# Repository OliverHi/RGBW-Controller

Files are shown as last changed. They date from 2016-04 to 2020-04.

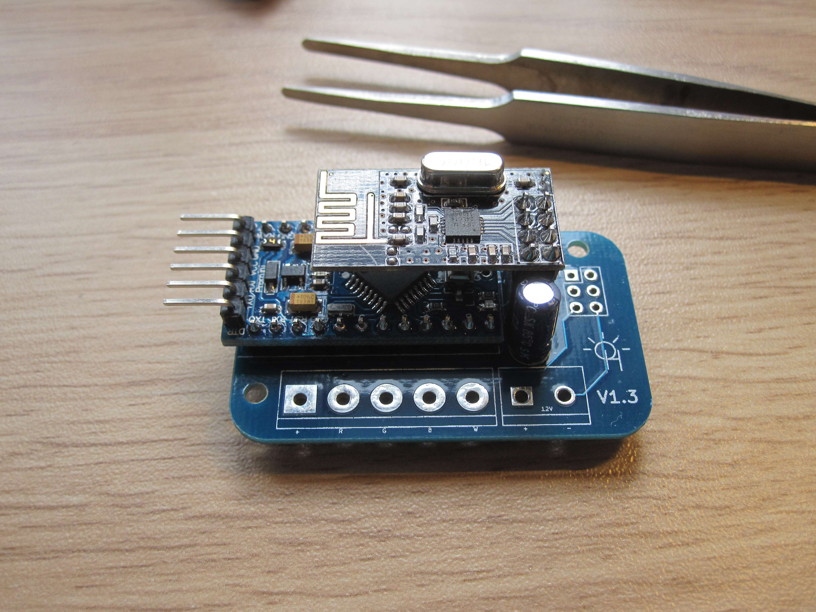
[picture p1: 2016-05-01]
Pictures/RGBWController004.jpg

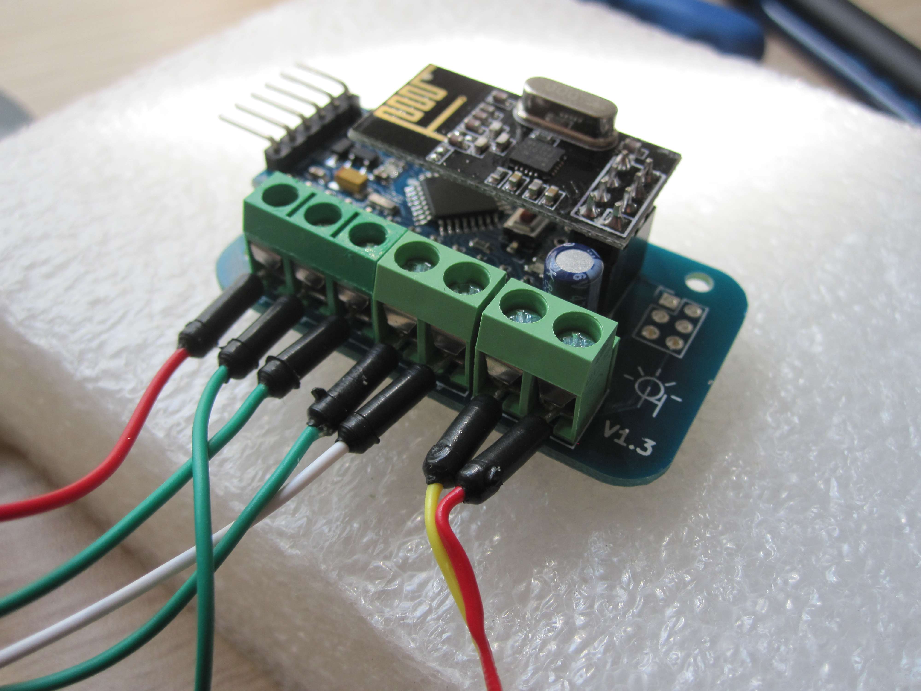
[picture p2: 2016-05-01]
Pictures/RGBWController012.jpg

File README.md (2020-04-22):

# Analog-RGBW-Controller
This is my rgbw controller project, where I am building a mysensors node to controll an analog RGBW led strip. 
The hardware is build around the arduino pro mini and NRF24L01+. 
The software is build on the MySensors project and is currently designed to work with Domoticz, Openhab 2 and homeAssistant (experimental) as a controller.

More infos can be found here: https://www.openhardware.io/view/74/MySensors-RGBW-Controller

## Project frozen/final
This project is done from my side. It has been working for years but I switched to another solution so I won't update this anymore. Feel free to send me Pull Requests though if you want anything updated or fork this repo.

If you are looking for a replacement follow me on [my blog](https://thesmarthomejourney.com/blog/) to see my current solution.

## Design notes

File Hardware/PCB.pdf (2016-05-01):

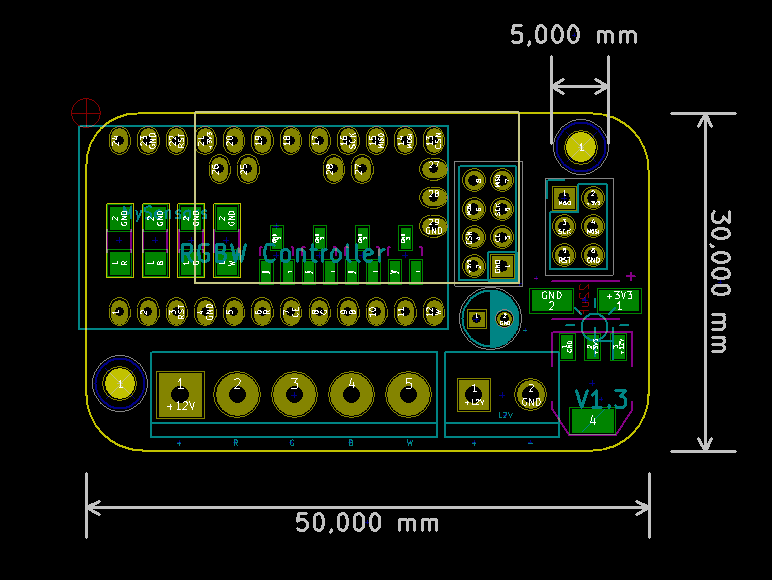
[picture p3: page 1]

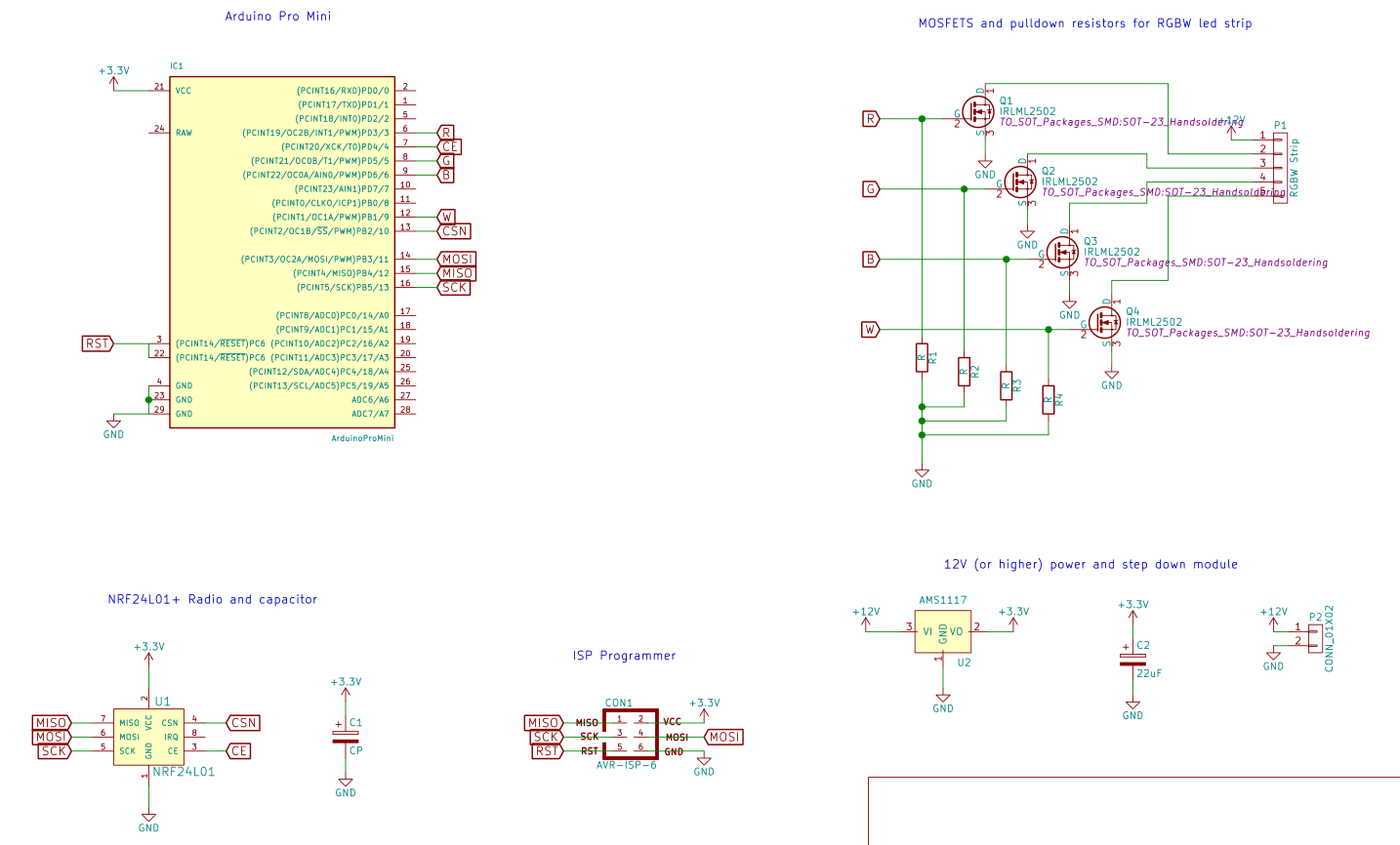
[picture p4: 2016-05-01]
Hardware/SchaltplanRGBW.PNG

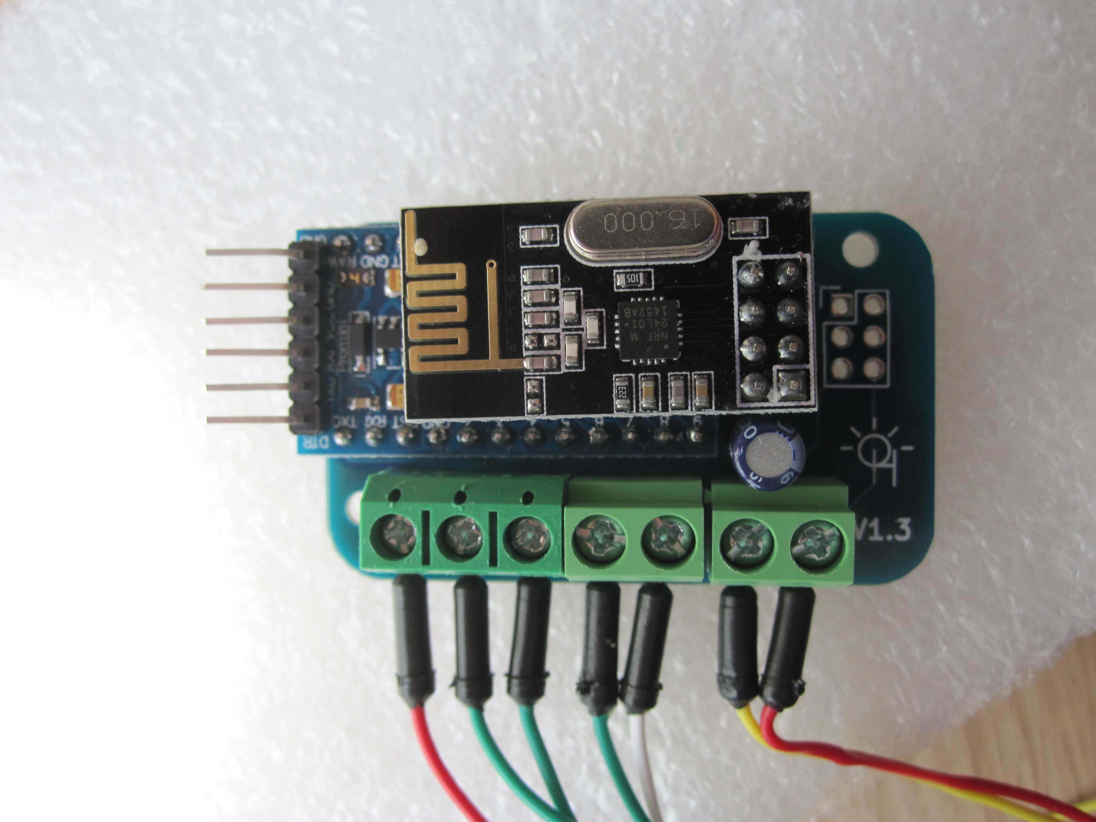
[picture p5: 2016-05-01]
Pictures/RGBWController013.jpg

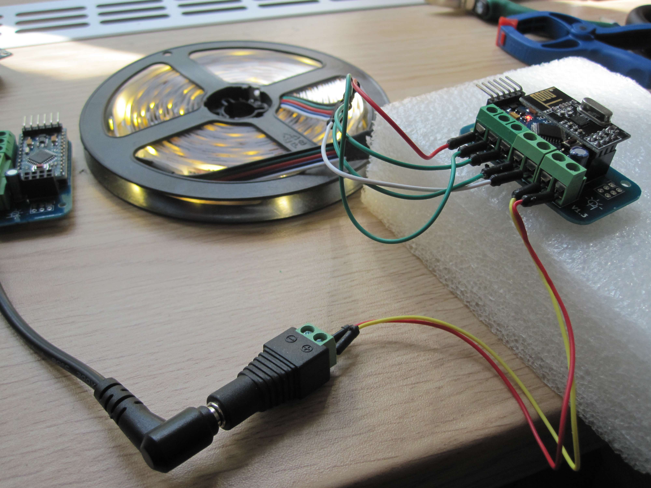
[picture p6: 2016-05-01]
Pictures/RGBWController011.jpg

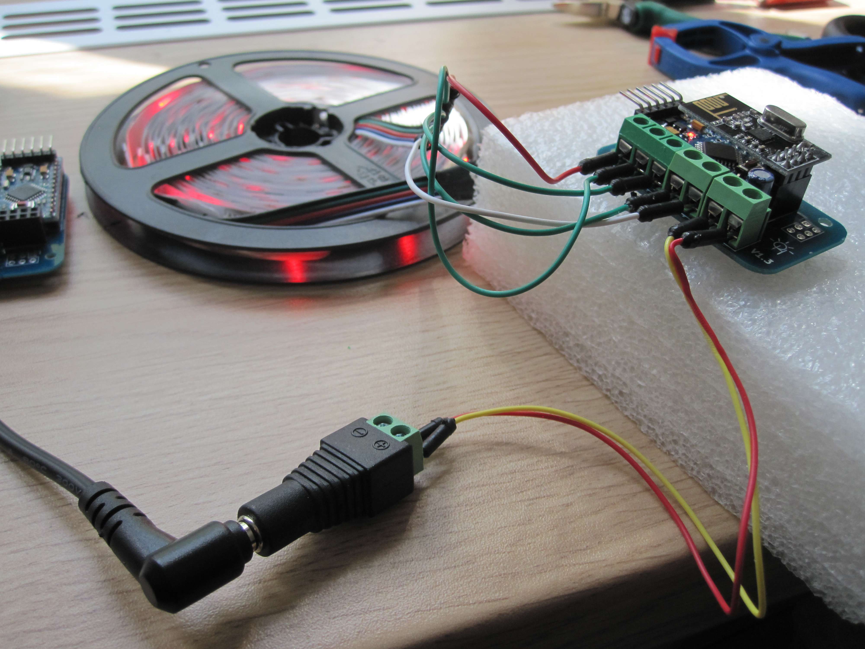
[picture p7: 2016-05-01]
Pictures/RGBWController010.jpg

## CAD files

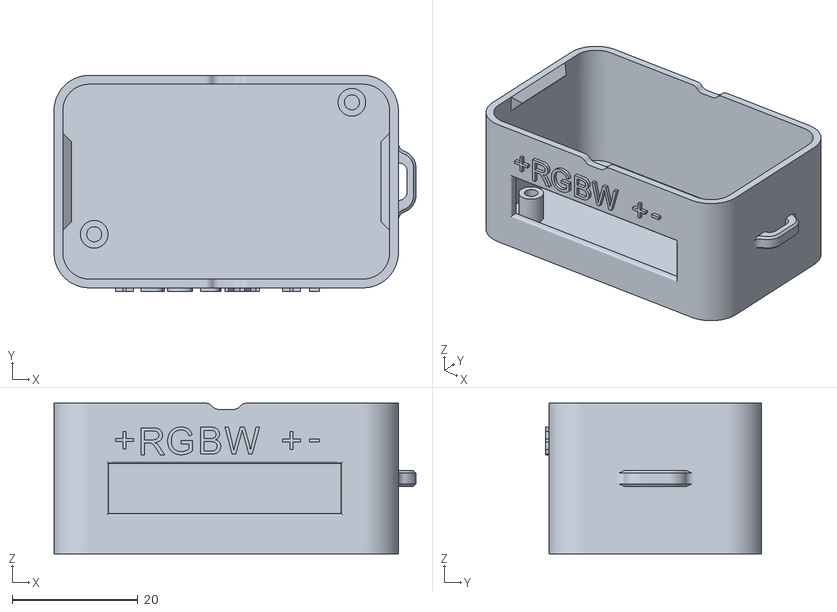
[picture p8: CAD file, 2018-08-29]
Hardware/Case/rgbwCaseBottomV2.stl
57.6 x 34.4 x 24.0

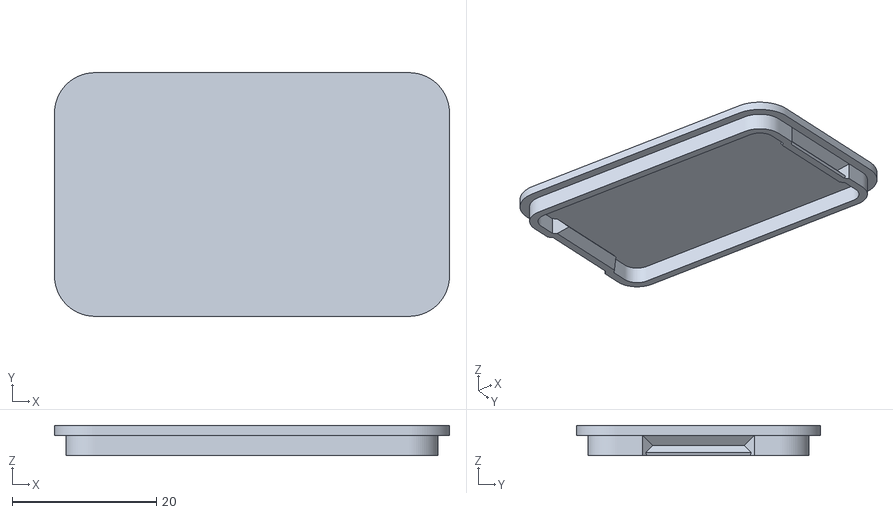
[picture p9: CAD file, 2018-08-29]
Hardware/Case/rgbwCaseTopV2.stl
54.8 x 33.8 x 4.20

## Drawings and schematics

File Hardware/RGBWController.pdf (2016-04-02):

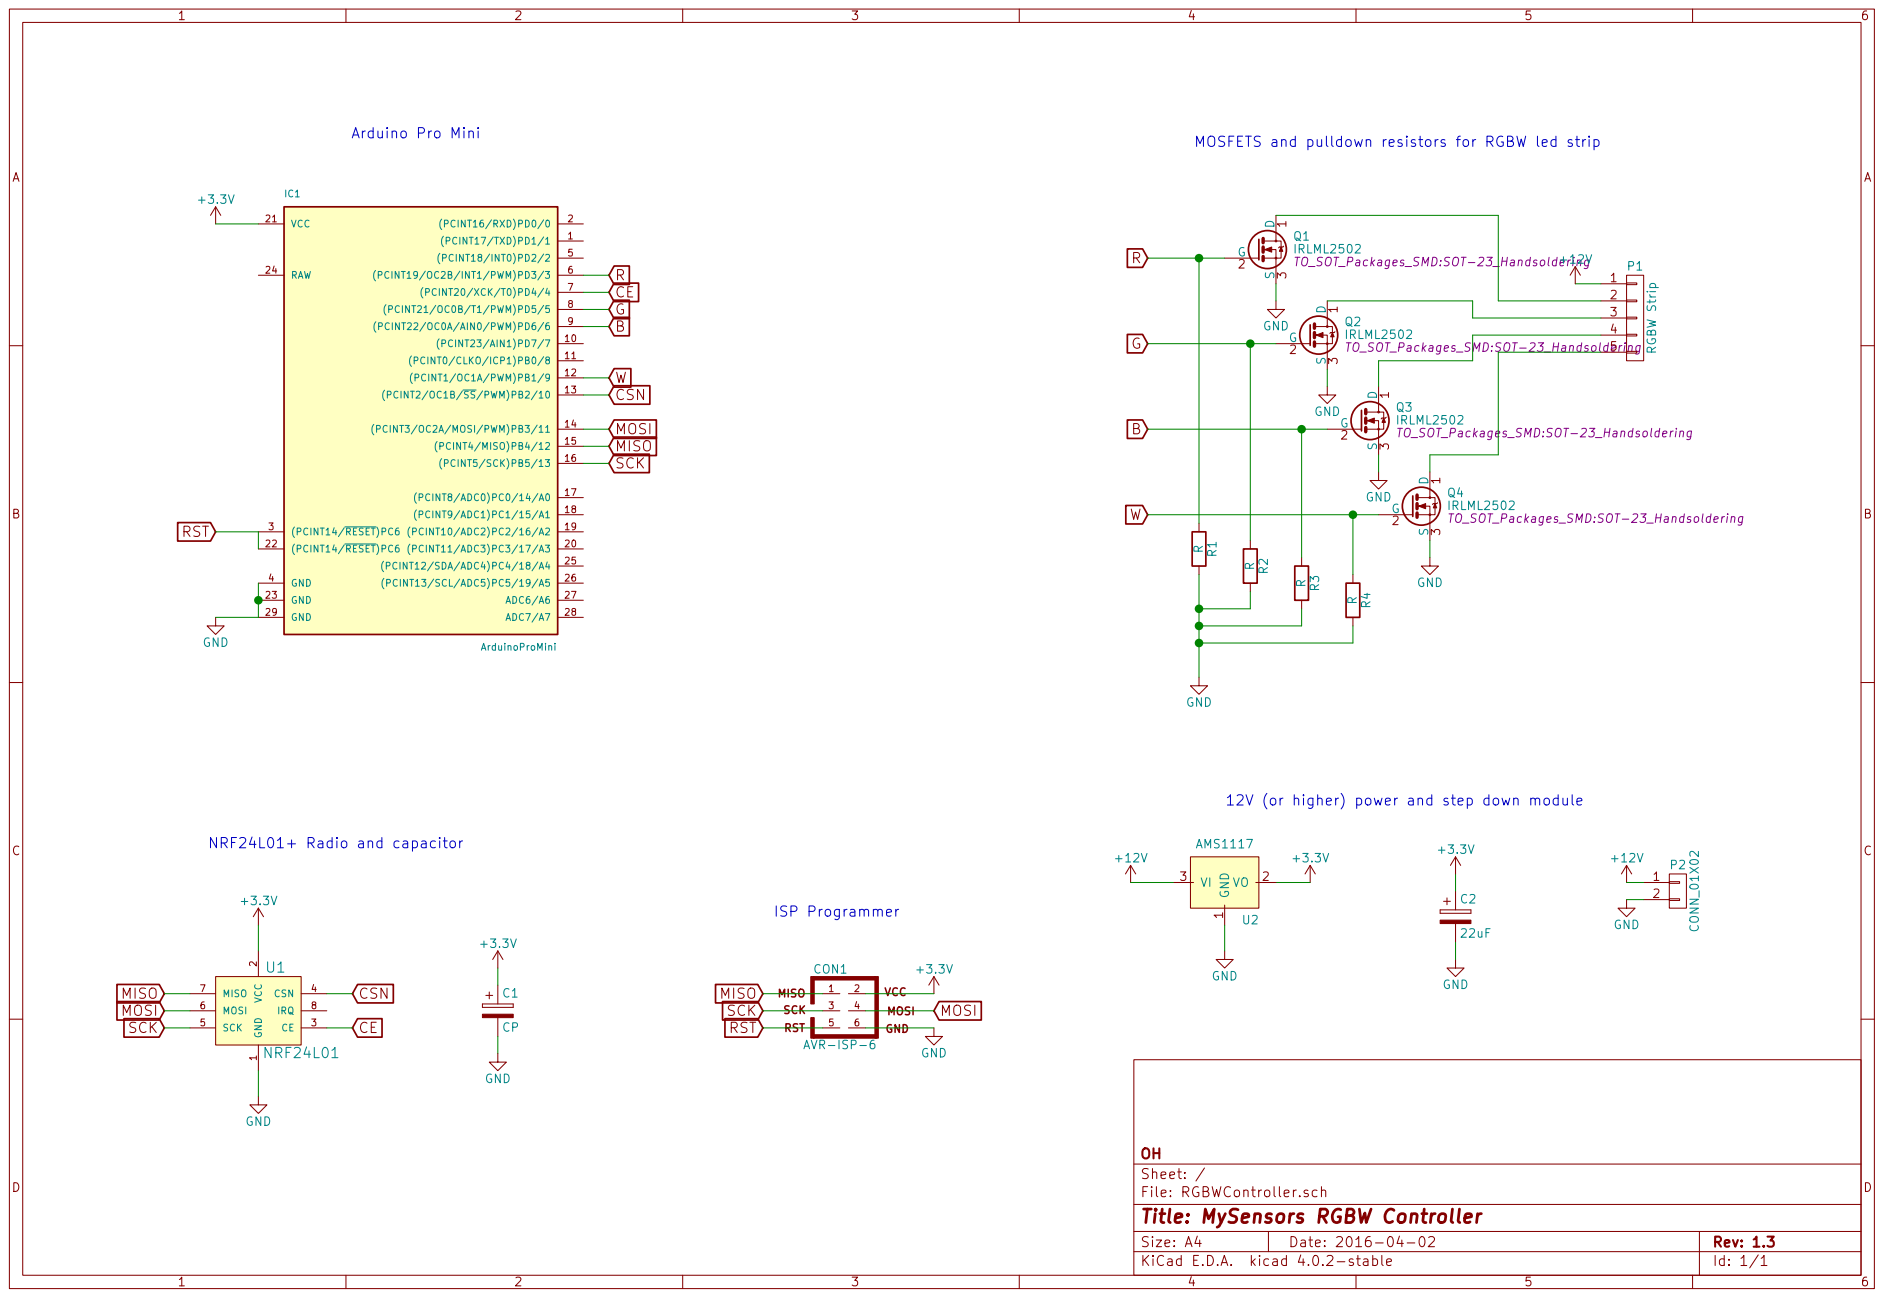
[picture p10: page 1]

Arduino Pro Mini NRF24L01+ Radio and capacitor

MOSFETS and pulldown resistors for RGBW led strip

RR4 RR3 RR2 RR1 GND GND GND GND GND

12V (or higher) power and step down module

2 CE 3 CSN 4 SCK 5 MOSI 6 MISO 7

Id: 1/1 Title: MySensors RGBW Controller File: RGBWController.sch Sheet: / OH

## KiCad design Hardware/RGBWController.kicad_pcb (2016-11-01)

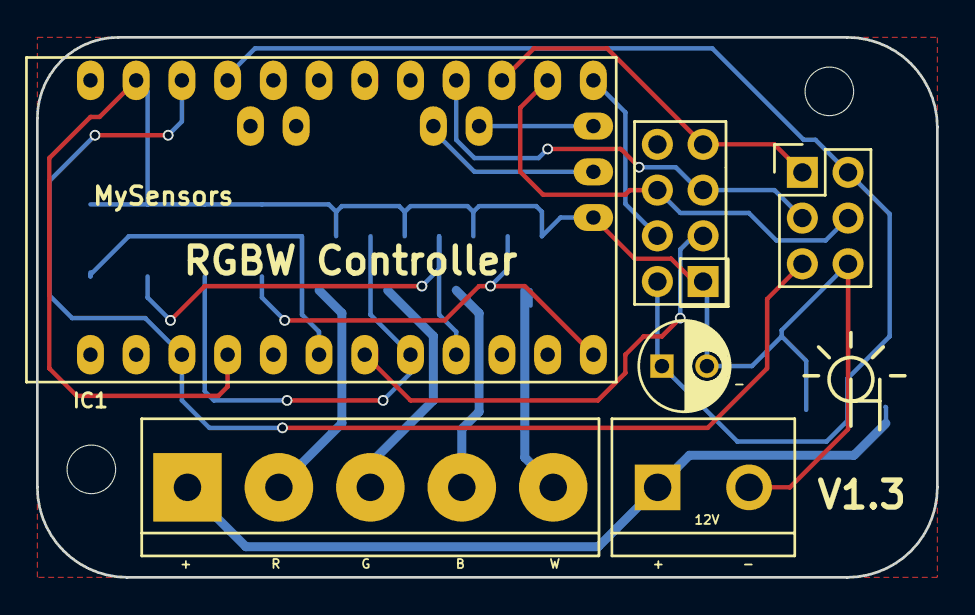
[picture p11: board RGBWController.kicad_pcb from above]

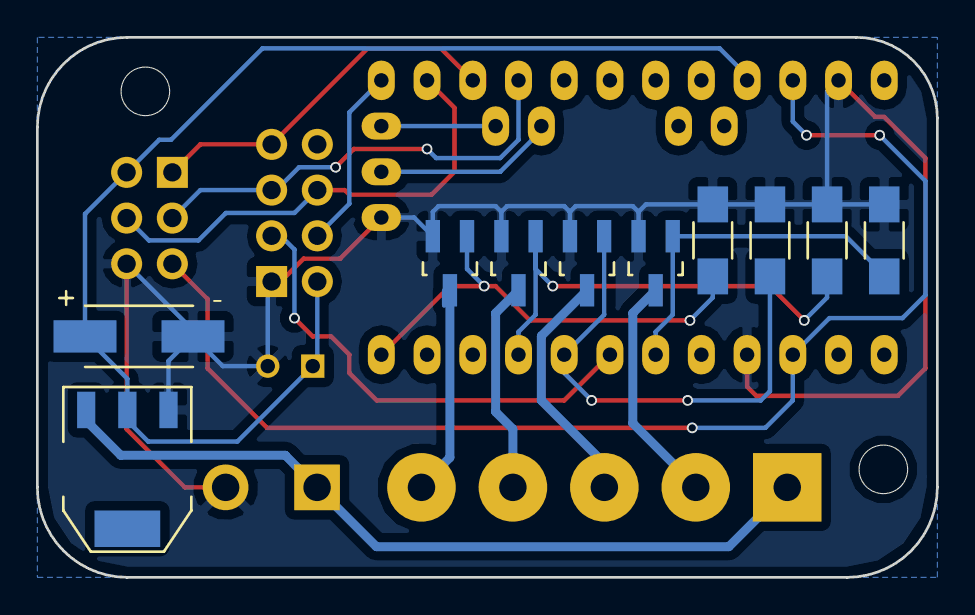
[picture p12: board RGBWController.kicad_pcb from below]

Board: 2 copper layers, 50.0 x 30.0 mm, 16 parts (10 on the bottom side), 17 nets.

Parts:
C1: CP; C_Radial_D5_L11_P2.5
C2: 22uF; TantalC_SizeC_EIA-6032_HandSoldering
CON1: AVR-ISP-6; Pin_Header_Straight_2x03
IC1: ArduinoProMini; pro_mini
P1: RGBW Strip; bornier5
P2: CONN_01X02; bornier2
Q1, Q2, Q3, Q4: IRLML2502; SOT-23_Handsoldering
R1, R2, R3, R4: R; R_1206_HandSoldering
U1: NRF24L01
U2: AMS1117; SOT-223

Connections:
+3V3: C1.1, C2.1, CON1.2, IC1.21, U1.2, U2.2
+12V: P1.1, P2.1, U2.3
B: IC1.9, Q3.1, R3.1
CE: IC1.7, U1.3
CSN: IC1.13, U1.4
G: IC1.8, Q2.1, R2.1
GND: C1.2, C2.2, CON1.6, IC1.4, IC1.23, IC1.29, P2.2, Q1.2, Q2.2, Q3.2, Q4.2, R1.2, R2.2, R3.2, R4.2, U1.1, U2.1
MISO: CON1.1, IC1.15, U1.7
MOSI: CON1.4, IC1.14, U1.6
unnamed: P1.2, Q1.3
unnamed: P1.3, Q2.3
unnamed: P1.4, Q3.3
unnamed: P1.5, Q4.3
R: IC1.6, Q1.1, R1.1
RST: CON1.5, IC1.3, IC1.22
SCK: CON1.3, IC1.16, U1.5
W: IC1.12, Q4.1, R4.1

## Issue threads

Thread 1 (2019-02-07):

Ask about hardwear

pepeEL, 2019-02-07:
Hi
I ask for you. In your project use arduino pro mini 5V or 3,3V ? I want use it with radio  RFM69HW on adapter from NRF24 to RFM69.

OliverHi, 2019-02-08:
> Hi
> I ask for you. In your project use arduino pro mini 5V or 3,3V ? I want use it with radio RFM69HW on adapter from NRF24 to RFM69.

In this case I used the 3.3V version. Take a look at the [schematics](https://github.com/OliverHi/RGBW-Controller/blob/master/Hardware/SchaltplanRGBW.PNG). I decided to do that because the NRF24 needs 3.3V and this way I can use the same power source (a AMS1117 3.3V converter). You could go with 5V though if the RFM69 can handle that and use the 5V pro mini or the onboard converter.

I can't help you with the RFM69HW modules though as I have been using NRF24's only.

pepeEL, 2019-02-08:
Thanks for reply. Rfm69 also use3. 3v
Thanks

pepeEL, 2019-02-08:
I build your project and use radio RFM69HW with this adapter:
https://www.openhardware.io/view/601/NRF24-to-RFM69-adapter
and Arduino Mini Pro 3,3V and not working. This device not communicate with my Gateway on my RPI3b+.

Ofcourse in RGBWDimmerV2.ino i change communicate type radio and add for my and also change to number 1 "#define ACK_COMMANDS 0 // set to 1/true " becuase i want use it with Home Assistant.

Tell me is any chance to you convert project also to use radio RFM69HW without adapter ?

Or can you share me project file to i can try rebuild it to use radio RFM69HW without adapter ?

pepeEL, 2019-02-09:
in serial monitor i have this after start....
 __  __       ____
|  \/  |_   _/ ___|  ___ _ __  ___  ___  _ __ ___
| |\/| | | | \___ \ / _ \ `_ \/ __|/ _ \| `__/ __|
| |  | | |_| |___| |  __/ | | \__ \  _  | |  \__ \
|_|  |_|\__, |____/ \___|_| |_|___/\___/|_|  |___/
        |___/                      2.2.0

16 MCO:BGN:INIT NODE,CP=RPNNA---,VER=2.2.0
26 TSM:INIT
28 TSF:WUR:MS=0
131 !TSM:INIT:TSP FAIL
133 TSM:FAIL:CNT=1
135 TSM:FAIL:DIS
137 TSF:TDI:TSL
10139 TSM:FAIL:RE-INIT
10141 TSM:INIT
10244 !TSM:INIT:TSP FAIL
10246 TSM:FAIL:CNT=2
10248 TSM:FAIL:DIS
10250 TSF:TDI:TSL
20254 TSM:FAIL:RE-INIT
20256 TSM:INIT
20361 !TSM:INIT:TSP FAIL
20363 TSM:FAIL:CNT=3
20365 TSM:FAIL:DIS
20367 TSF:TDI:TSL

pepeEL, 2019-02-09:
replace radio and now show
 __  __       ____
|  \/  |_   _/ ___|  ___ _ __  ___  ___  _ __ ___
| |\/| | | | \___ \ / _ \ `_ \/ __|/ _ \| `__/ __|
| |  | | |_| |___| |  __/ | | \__ \  _  | |  \__ \
|_|  |_|\__, |____/ \___|_| |_|___/\___/|_|  |___/
        |___/                      2.2.0

16 MCO:BGN:INIT NODE,CP=RPNNA---,VER=2.2.0
26 TSM:INIT
28 TSF:WUR:MS=0
30 TSM:INIT:TSP OK
32 TSM:FPAR
1034 TSF:MSG:SEND,255-255-255-255,s=255,c=3,t=7,pt=0,l=0,sg=0,ft=0,st=OK:
3043 !TSM:FPAR:NO REPLY
3045 TSM:FPAR
4048 TSF:MSG:SEND,255-255-255-255,s=255,c=3,t=7,pt=0,l=0,sg=0,ft=0,st=OK:
6060 !TSM:FPAR:NO REPLY
6062 TSM:FPAR
7065 TSF:MSG:SEND,255-255-255-255,s=255,c=3,t=7,pt=0,l=0,sg=0,ft=0,st=OK:
9074 !TSM:FPAR:NO REPLY
9076 TSM:FPAR
10078 TSF:MSG:SEND,255-255-255-255,s=255,c=3,t=7,pt=0,l=0,sg=0,ft=0,st=OK:
12087 !TSM:FPAR:FAIL
12089 TSM:FAIL:CNT=1
12091 TSM:FAIL:DIS
12093 TSF:TDI:TSL
22097 TSM:FAIL:RE-INIT
22099 TSM:INIT
22102 TSM:INIT:TSP OK
22104 TSM:FPAR
23107 TSF:MSG:SEND,255-255-255-255,s=255,c=3,t=7,pt=0,l=0,sg=0,ft=0,st=OK:
25116 !TSM:FPAR:NO REPLY
25118 TSM:FPAR
26120 TSF:MSG:SEND,255-255-255-255,s=255,c=3,t=7,pt=0,l=0,sg=0,ft=0,st=OK:
28129 !TSM:FPAR:NO REPLY
28131 TSM:FPAR
29134 TSF:MSG:SEND,255-255-255-255,s=255,c=3,t=7,pt=0,l=0,sg=0,ft=0,st=OK:
31145 !TSM:FPAR:NO REPLY
31148 TSM:FPAR
32151 TSF:MSG:SEND,255-255-255-255,s=255,c=3,t=7,pt=0,l=0,sg=0,ft=0,st=OK:
34160 !TSM:FPAR:FAIL
34162 TSM:FAIL:CNT=2
34164 TSM:FAIL:DIS
34166 TSF:TDI:TSL
44169 TSM:FAIL:RE-INIT
44171 TSM:INIT
44173 TSM:INIT:TSP OK
44175 TSM:FPAR
45178 TSF:MSG:SEND,255-255-255-255,s=255,c=3,t=7,pt=0,l=0,sg=0,ft=0,st=OK:
47190 !TSM:FPAR:NO REPLY
47192 TSM:FPAR
48195 TSF:MSG:SEND,255-255-255-255,s=255,c=3,t=7,pt=0,l=0,sg=0,ft=0,st=OK:
50204 !TSM:FPAR:NO REPLY
50206 TSM:FPAR
51208 TSF:MSG:SEND,255-255-255-255,s=255,c=3,t=7,pt=0,l=0,sg=0,ft=0,st=OK:
53217 !TSM:FPAR:NO REPLY
53219 TSM:FPAR
54222 TSF:MSG:SEND,255-255-255-255,s=255,c=3,t=7,pt=0,l=0,sg=0,ft=0,st=OK:
56233 !TSM:FPAR:FAIL
56236 TSM:FAIL:CNT=3
56238 TSM:FAIL:DIS
56240 TSF:TDI:TSL
66244 TSM:FAIL:RE-INIT
66246 TSM:INIT
66248 TSM:INIT:TSP OK
66250 TSM:FPAR
67252 TSF:MSG:SEND,255-255-255-255,s=255,c=3,t=7,pt=0,l=0,sg=0,ft=0,st=OK:
69261 !TSM:FPAR:NO REPLY
69263 TSM:FPAR
70266 TSF:MSG:SEND,255-255-255-255,s=255,c=3,t=7,pt=0,l=0,sg=0,ft=0,st=OK:
72278 !TSM:FPAR:NO REPLY
72280 TSM:FPAR
73283 TSF:MSG:SEND,255-255-255-255,s=255,c=3,t=7,pt=0,l=0,sg=0,ft=0,st=OK:
75292 !TSM:FPAR:NO REPLY
75294 TSM:FPAR
76296 TSF:MSG:SEND,255-255-255-255,s=255,c=3,t=7,pt=0,l=0,sg=0,ft=0,st=OK:

OliverHi, 2019-04-20:
All files of the project are in this repo. Feel free to change and update stuff (as long as you link my repo if you upload your code). I wont create an extra version for the RFM69 (no time). It should just work though with what you posted though I think. But for more help please head over to the mysensors forum

Closed 2019-04-20.

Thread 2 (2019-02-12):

Implement button to turn leds color WHITE

pepeEL, 2019-02-12:
Hi
Is any chance to implement in your sketch option to add manual button to enable LEDS color WHITE ?
Any color i want to setup by gateway but on the wall i want mount switch to enable color white and also to disable.
Please add this if you can... In sketch setup pin on which button works and also color which should be turn on....

OliverHi, 2019-04-20:
What do you mean by Leds color white? If you want to add a button to your board that switches on the white lights just add standard (non blocking) button code (a quick search for arduino button should get you there) and call the void `updateColor(const char* newColor)` with your color of choice. Or send a message to your gateway and handle the logic in your controller (better solution imho)

pepeEL, 2019-04-21:
Yes I want add button to RGBW which turn on led with color white.
But how add it and how configure it in sketch and also how phisical add to this arduino?

OliverHi, 2019-04-21:
This is really outside of the scope of this repo. I told you how to do it, I wont code this for you. Once you have tried and it still does not work there are enough forums out there for arduino questions.

Closed 2019-04-20.

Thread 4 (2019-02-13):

Bug in project PCB

pepeEL, 2019-02-13:
I found one bug in your project PCB. Pin from radio nae IRQ should be connect on PCB to pin 2 ARDUINO. But it is not connect. Also when i use radio RFM69HW i also need connect PIN 2 Arduino to pin DI00 on radio RFM69HW. This should be correct... Now pin 9 from radio is not connect to any pin Arduino.

OliverHi, 2019-04-20:
You are right I think. The IRQ pin is not connected because it is not required when using the NRF24L01 which this board is based around. Maybe there are also other pins needed for the RFM69HW but I am not really supporting that.
This project is frozen from my side (as I am using other solutions now). But feel free to update everything you want (all code is in this repo) and create a pull request. I will review and merge it as soon as possible

Closed 2020-04-22.

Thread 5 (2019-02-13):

Initial state-OFF

pepeEL, 2019-02-13:
Hi
Is any chance to implement in sketch option to Node after connect power go to state OFF. Now it go to ON. In situation when power lost and come back all leds will be ON.

OliverHi, 2019-04-20:
Yes you can change the initial state of the node in my code. Have a look [at these lines.](https://github.com/OliverHi/RGBW-Controller/blob/3e6f01034f0cd9d36f983cb69602abfd6884ea8d/Software/RGBWDimmerV2/RGBWDimmerV2.ino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) Changing `target_values` and `values` according to your needs will get you there

pepeEL, 2019-04-21:
But if I want to have OFF when power is on how I must change this code initial and target?

OliverHi, 2019-04-21:
Those are RGBW values so of is 0 0 0 0. The rest you have to figure out on your own.

Closed 2019-04-20.

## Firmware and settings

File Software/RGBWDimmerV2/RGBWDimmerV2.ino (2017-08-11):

/**
Based on the MySensors Project: http://www.mysensors.org

This sketch controls a (analog)RGBW strip by listening to new color/dimmer/status values from a (domoticz/openhab/Homeassistant) controller and then fading to the new color.

Version 2.2 - Added initial state messages to the controller and ack messages to support home-assistant, also added better nonlinear fading (thanks to Jan Gatzke from the forum)
Version 2.1 - Changed conversion to also work with openhab(2)
Version 2.0 - Updated to MySensors 2 and changed fading
Version 1.0 - Changed pins and gw definition
Version 0.9 - Oliver Hilsky
*/


#define SN   "Name"
#define SV   "v2.2 0108017"

// library settings
#define MY_RF24_CE_PIN 4                  // Radio specific settings for RF24 - changed this!
#define MY_RF24_CS_PIN 10                 // Radio specific settings for RF24 (you'll find similar config for RFM69)
#define MY_RADIO_NRF24                    // Use the nrf24 to send messages
#define MY_DEBUG                          // Enables debug messages in the serial log
#define MY_BAUD_RATE  115200              // Sets the serial baud rate for console
#define MY_SIGNING_SOFT                   // Enables software signing
#define MY_SIGNING_REQUEST_SIGNATURES     // Always request signing from gateway
#define MY_SIGNING_SOFT_RANDOMSEED_PIN 7  // floating pin for randomness
#define MY_SIGNING_NODE_WHITELISTING {{.nodeId = GATEWAY_ADDRESS,.serial = {0x01,0x01,0x01,0x01,0x01,0x01,0x01,0x01,0x01}}} // add your gateway address here!


#include <SPI.h>
#include <MyConfig.h>
#include <MySensors.h>
#include <Vcc.h>

// ID for the presentation at the gateway
#define RGBW_ID 1

// Arduino pin attached to driver pins
#define RED_PIN 3 
#define WHITE_PIN 9
#define GREEN_PIN 5
#define BLUE_PIN 6
#define NUM_CHANNELS 4 // how many channels, RGBW=4 RGB=3...

// Smooth stepping between the values
#define STEP 1
#define INTERVAL 10

#define ACK_COMMANDS 0 // set to 1/true if you use home assistant. This will answer every message with the same, disable otherwise
   
// Stores the current color settings
byte channels[4] = {RED_PIN, GREEN_PIN, BLUE_PIN, WHITE_PIN};
byte values[4] = {0, 0, 0, 0}; // initial values -> makes white fade up to 100%
byte target_values[4] = {0, 0, 0, 255};
//Stores corrected values for each step from 0 to 255. See https://diarmuid.ie/blog/pwm-exponential-led-fading-on-arduino-or-other-platforms/
byte converted_values[256] = {0,0,0,0,0,0,0,0,0,0,0,0,0,0,0,0,0,0,0,1,1,1,1,1,1,1,1,1,1,1,1,1,1,1,1,1,1,1,1,1,1,1,1,2,2,2,2,2,2,2,2,2,2,2,2,2,2,2,3,3,3,3,3,3,3,3,3,3,3,3,4,4,4,4,4,4,4,4,4,5,5,5,5,5,5,5,5,6,6,6,6,6,6,7,7,7,7,7,7,8,8,8,8,8,9,9,9,9,9,10,10,10,10,11,11,11,11,12,12,12,13,13,13,13,14,14,14,15,15,15,16,16,17,17,17,18,18,19,19,20,20,20,21,21,22,22,23,23,24,24,25,26,26,27,27,28,29,29,30,31,31,32,33,34,34,35,36,37,38,38,39,40,41,42,43,44,45,46,47,48,49,50,51,52,54,55,56,57,58,60,61,62,64,65,67,68,70,71,73,75,76,78,80,81,83,85,87,89,91,93,95,97,99,101,104,106,108,111,113,116,118,121,123,126,129,132,135,138,141,144,147,150,154,157,161,164,168,171,175,179,183,187,191,195,200,204,209,213,218,223,228,233,238,243,249,255};

// Messages
MyMessage statusMessage(RGBW_ID, V_STATUS);
MyMessage dimmerMessage(RGBW_ID, V_DIMMER);
MyMessage colorMessage (RGBW_ID, V_RGBW);

// stores dimming level
byte dimming = 100;
byte target_dimming = 100;

// tracks if the strip should be on of off
boolean isOn = true;

// time tracking for updates
unsigned long lastupdate = millis();
     
void presentation() 
{
  // Present sketch (name, version)
  sendSketchInfo(SN, SV);				
       
  // Register sensors (id, type, description, ack back)
  present(RGBW_ID, S_RGBW_LIGHT);

  // get old values if this is just a restart
  request(RGBW_ID, V_RGBW);
}

void setup() {

  // Set all channels to output (pin number, type)
  for (int i = 0; i < NUM_CHANNELS; i++) {
    pinMode(channels[i], OUTPUT);
  }

  // init lights
  updateLights();
 
  Serial.println("Waiting for messages...");  
}

void loop()
{
  // and set the new light colors
  if (millis() > lastupdate + INTERVAL) {
    updateLights();
    lastupdate = millis();
  }

  // send initial state (needed to be detected by home assistant)
  static bool first_message_sent = false;

  if ( first_message_sent == false ) {
    Serial.println( "Sending initial state..." );
    sendinitialValuesToGateway();
    first_message_sent = true;
  }
}

void sendinitialValuesToGateway() {
  send(colorMessage.set("000000ff")); // full white
  send(statusMessage.set(isOn)); // on
  send(dimmerMessage.set(target_dimming)); // dimmed to start level
}

// callback function for incoming messages
void receive(const MyMessage &message) {

  Serial.print("Got a message - ");
  Serial.print("Messagetype is: ");
  Serial.println(message.type);

  // acknowledgement
  if (message.isAck())
  {
   	Serial.println("Got ack from gateway");
  }
  
  // new dim level
  else if (message.type == V_DIMMER) {
    Serial.println("Dimming to ");
    Serial.println(message.getString());
    updateDimmer(message.getByte());
  }

  // on / off message
  else if (message.type == V_STATUS) {
    updateStatus(message.getInt());
    
    String statusMsg = "Turning light ";
    statusMsg += (message.getInt() == 0 ? ("off") : ("on"));
    Serial.println(statusMsg);
  }

  // new color value
  else if (message.type == V_RGBW) {    
    Serial.println("Got new color");

    updateColor(message.getString());
  }  
}

void updateDimmer(byte newDimValue) {
  target_dimming = newDimValue;

  if (ACK_COMMANDS) {
    send(dimmerMessage.set(newDimValue)); // send acknowledgement
  }

  if (newDimValue > 0) {
    isOn = true; // a new dimmer value also means on, no seperate signal gets send (by domoticz)

    if (ACK_COMMANDS) {
      send(statusMessage.set(isOn)); // send acknowledgement
    }
  }
}

void updateStatus(int newStatus) {
  isOn = newStatus;

  if (ACK_COMMANDS) {
    send(statusMessage.set(newStatus)); // send acknowledgement
  }
}

void updateColor(const char* newColor) {
  inputToRGBW(newColor);  

  if (ACK_COMMANDS) {
    send(colorMessage.set(newColor)); // send acknowledgement
  }

  // a new color also means on, no seperate signal gets send (by domoticz); needed e.g. for groups
  isOn = true; 
  
  if (ACK_COMMANDS) {
    send(statusMessage.set(isOn)); // send acknowledgement
  }
}

// this gets called every INTERVAL milliseconds and updates the current pwm levels for all colors
void updateLights() {  

  // update pin values -debug
  // Serial.println(greenval);
  // Serial.println(redval);
  // Serial.println(blueval);
  // Serial.println(whiteval);

  // Serial.println(target_greenval);
  // Serial.println(target_redval);
  // Serial.println(target_blueval);
  // Serial.println(target_whiteval);
  // Serial.println("+++++++++++++++");

  // for each color
  for (int v = 0; v < NUM_CHANNELS; v++) {

    if (values[v] < target_values[v]) {
      values[v] += STEP;
      if (values[v] > target_values[v]) {
        values[v] = target_values[v];
      }
    }

    if (values[v] > target_values[v]) {
      values[v] -= STEP;
      if (values[v] < target_values[v]) {
        values[v] = target_values[v];
      }
    }
  }

  // dimming
  if (dimming < target_dimming) {
    dimming += STEP;
    if (dimming > target_dimming) {
      dimming = target_dimming;
    }
  }
  if (dimming > target_dimming) {
    dimming -= STEP;
    if (dimming < target_dimming) {
      dimming = target_dimming;
    }
  }

  // debug - new values
  // Serial.println(greenval);
  // Serial.println(redval);
  // Serial.println(blueval);
  // Serial.println(whiteval);

  // Serial.println(target_greenval);
  // Serial.println(target_redval);
  // Serial.println(target_blueval);
  // Serial.println(target_whiteval);
  // Serial.println("+++++++++++++++");

  // set actual pin values
  for (int i = 0; i < NUM_CHANNELS; i++) {
    if (isOn) {
      // normal fading
      analogWrite(channels[i], dimming / 100.0 * values[i]);

      //Fading with corrected values see https://diarmuid.ie/blog/pwm-exponential-led-fading-on-arduino-or-other-platforms/ - currently crashing
      //analogWrite(channels[i], dimming / 100.0 * converted_values[values[i]]);
    } else {
      analogWrite(channels[i], 0);
    }
  }
}

// converts incoming color string to actual (int) values
// ATTENTION this currently does nearly no checks, should work with domoticz / home assistant / openhab 2 though
void inputToRGBW(const char * input) {
  Serial.print("Got color value of length: "); 
  Serial.println(strlen(input));
  
  if (strlen(input) == 6) {
    Serial.println("new rgb value");
    target_values[0] = fromhex (& input [0]);
    target_values[1] = fromhex (& input [2]);
    target_values[2] = fromhex (& input [4]);
    target_values[3] = 0;
  } else if (strlen(input) == 8) { // from openhab / home assistant
    Serial.println("new rgbw value 8");
    target_values[0] = fromhex (& input [0]);
    target_values[1] = fromhex (& input [2]);
    target_values[2] = fromhex (& input [4]);
    target_values[3] = fromhex (& input [6]);
  } else if (strlen(input) == 9) { // from domoticz
    Serial.println("new rgbw value 9");
    target_values[0] = fromhex (& input [1]); // ignore # as first sign
    target_values[1] = fromhex (& input [3]);
    target_values[2] = fromhex (& input [5]);
    target_values[3] = fromhex (& input [7]);
  } else {
    Serial.println("Wrong length of input");
  }  


  Serial.print("New color values: ");
  Serial.println(input);
  
  // for (int i = 0; i < NUM_CHANNELS; i++) {
  //   Serial.print(target_values[i]);
  //   Serial.print(", ");
  // }
 
  // Serial.println("");
  // Serial.print("Dimming: ");
  // Serial.println(dimming);
}

// converts hex char to byte
byte fromhex (const char * str)
{
  char c = str [0] - '0';
  if (c > 9)
    c -= 7;
  int result = c;
  c = str [1] - '0';
  if (c > 9)
    c -= 7;
  return (result << 4) | c;
}

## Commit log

2015-11-30 updated readme for the change from esp to mysensors/arduino
2015-11-30 added arduino sketch
2015-12-10 added PCB design + Gerber files
2016-03-12 fixed some errors in the software
    [RGBWDimmer.ino]
2016-04-02 added schema/pcb kicad files for the next version of the board
    [RGBWController.kicad_pcb, RGBWController.sch]
2016-05-01 added pictures for the PCB/Schematics
2016-11-01 better update with new gerber files
    [RGBWController.kicad_pcb]
2016-11-02 added all gerber exports, fixed gerber zip file
    [RGBWController-B.Cu.gbl, RGBWController-B.Mask.gbs, RGBWController-B.SilkS.gbo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]
2017-08-11 fixed switched on/off log statements
    [RGBWDimmerV2.ino]
2018-08-29 added stl files for the case
    [rgbwCaseBottomV2.stl, rgbwCaseTopV2.stl]
